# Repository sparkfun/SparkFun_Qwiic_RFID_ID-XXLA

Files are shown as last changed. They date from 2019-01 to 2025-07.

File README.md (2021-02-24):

SparkFun Qwiic RFID ID-XXLA
========================================

<table class="table table-hover table-striped table-bordered">
  <tr align="center">
   <td><a href="https://www.sparkfun.com/products/15191">RFID Qwiic Reader</a></td>
   <td><a href="https://www.sparkfun.com/products/15209">RFID Qwiic Kit</a></td>
  </tr>
  <tr align="center">
    <td><i>SparkFun RFID Qwiic Reader [<a href="https://www.sparkfun.com/products/15191">SEN-15191</a>]</i></td>
    <td><i>SparkFun RFID Qwiic Reader Kit [<a href="https://www.sparkfun.com/products/15209">KIT-15209</a>]<i></td>
  </tr>
</table>
     
The SparkFun Qwiic RFID ID-XXLA is a simple board that pairs with the ID-3LA, ID-12LA, ID-20LA, RFID modules.Utilizing the onboard ATtiny84A, the Qwiic RFID takes the six byte ID tag of your 125Khz RFID card, attaches a time stamp to it, and puts it onto a stack that holds up to 20 unique RFID scans at any given time. This information is easy to get at with some simple I2C commands and we’ve included some example code that shows you just how to do it using the broken out interrupt pin. We’ve also broken out two antennae pins that should only be used with the smaller ID-3LA.

The SparkFun Qwiic RFID has a buzzer and LED that indicates that card has been scanned. We’ve included a jumper to disconnect the buzzer, a jumper for the I2C pull-up resistors, an interrupt jumper, and finally an address jumper. The Qwiic RFID comes fully decked out in Qwiic connectors, no need to solder a thing, just plug it in and start scanning!

Repository Contents
-------------------

* **/Firmware** - The core sketch that runs the SparkFun Qwiic RFID ID-XXLA
* **/Arduino Examples** - A number of examples to show how to read buttons with time, change the I2C address and scan for I2C devices
* **/ATtiny Firmware** - Default firmware for the Qwiic RFID
* **/Hardware** - Eagle design files (.brd, .sch)

Documentation
--------------

* **[Hookup Guide](https://learn.sparkfun.com/tutorials/sparkfun-qwiic-rfid-idxxla-hookup-guide)** - Basic hookup guide.

Arduino Library 
----------------
* **[SparkFun Qwiic RFID Arduino Library](https://github.com/sparkfun/SparkFun_Qwiic_RFID_Arduino_Library)**

Python Package
----------------
* **[SparkFun Qwiic RFID Python Package](https://github.com/sparkfun/Qwiic_RFID_Py)**

Product Versions
----------------
* [SEN-15191](https://www.sparkfun.com/products/15191)- SparkFun Qwiic RFID ID-XXLA
* [KIT-15209](https://www.sparkfun.com/products/15209)- SparkFun Qwiic RFID ID-XXLA with ID Innovations RFID Module, Qwiic Cable, and RFID Tagged Cards, 

License Information
-------------------

This product is _**open source**_! 

Please review the LICENSE.md file for license information. 

If you have any questions or concerns on licensing, please contact techsupport@sparkfun.com.

Please use, reuse, and modify these files as you see fit. Please maintain attribution to SparkFun Electronics and release any derivative under the same license.

Distributed as-is; no warranty is given.

- Your friends at SparkFun.

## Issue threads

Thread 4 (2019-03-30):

Byts run together

pmartel, 2019-03-30:
### Subject of the issue
No separation between bytes in Example1_ReadTag.ino

### Your workbench
Windows 10, Arduino 1.6,6 and 1.8.9
* What version of the device are you using? Is there a firmware version?
USB
USB
* Are there any additional details that may help us help you?

### Steps to reproduce
Run it.  Notice that the bytes may be between 1 and 3 digits.  There is no clear separation between the bytes.
### Expected behaviour
Either put a separator between bytes, or express them in hex and put a '0' in front of '0' to 'f'
	for( int x = 0; x < TAG_REQUEST; x++ ) {
    tempTag = Wire.read();
    // Concatenating the bytes onto the end of "tagID".
    s = String(tempTag, HEX); // s is defined as a String
    if ( s.length() == 1) { // handle 00 through 0f
      s = "0"+s;
    }
    tagID += s;
  }
### Actual behaviour
bytes are ambiguous

edspark, 2019-04-01:
That's an interesting perspective. While the incoming bytes certainly could be broken up or printed out as a HEX, I don't see how that gives greater clarity to the RFID tag number because it _is_ that number. If you look at the datasheet for the module on the module's product page under the "Documents" tab found [here](https://www.sparkfun.com/products/11827). There is a section on page four that explains the format of the RFID tag number: five numerical values followed by a checksum of those five numbers. This is what's presented by the module to the SparkFun RFID IDxx-LA  and then passed to you the user.  It's like splitting the number 196 into it's individual numerical components (1 - 9 - 6), but really the number is 196.  Re-open the issue if I missed something. Thanks for issue!

pmartel, 2019-04-01:
Give that you know that there are 5 bytes and a checksum, I agree that you should be able to extract the bytes from a string of decimal digits.  However, if you want to verify the checksum, it becomes somewhat messy.
Here are the tag numbers for the 2 cards that came with my kit and another RFID device I have:
SparkFun Qwiic RFID, waiting for RFID to be scanned.
RFID Tag ID: 850898172147
RFID Tag ID: 850723432152
RFID Tag ID: 78097123228176

I wondered about the different lengths of the strings.  That led me to realize that there were no delimiters between the bytes and potential ambiguity.  If you had to take one of those RFID tag IDs and verify the checksum, how would you proceed?

edspark, 2019-04-02:
I like where you're brain is going! Before I begin, I want you to know that the module does a checksum on the bytes before it sends them serially to the SparkFun Qwiic RFID-IDxxLA, and then I unnecessarily do an _additional_ checksum on the number before I send it to the user. With that said, I would encourage you to read the datasheet (again page four) as it explains how it is done quite clearly with pictures, however I'll do my best to explain it in text.  Each column of bits of each _byte_ is exclusively or'ed (EXOR'ed) with each other to get the checksum.  If you wanted to get it done with provided code, you would print out each byte with the Serial.println(tempTag, BIN), then EXOR the first column of bits, then the second column bits, then the third, etc. and those EXOR'ed bits together will equal the sixth checksum byte.  Hope that helps.

pmartel, 2019-04-02:
Thanks, I'm familiar with checksums.  We used to do them on paper tape a long time ago.Given the individual bytes, it's straightforward to do a checksum, and of course the checksum of all 6 bytes should be 0.  I was just trying to point out that when the decimal representations of the bytes are merged together into a string, it's a bit tougher to verify the checksum.
Best wishes,--Phil
In a message dated 4/2/2019 12:44:45 Eastern Standard Time, notifications@github.com writes:

I like where you're brain is going! Before I begin, I want you to know that the module does a checksum on the bytes before it sends them serially to the SparkFun Qwiic RFID-IDxxLA, and then I unnecessarily do an additional checksum on the number before I send it to the user. With that said, I would encourage you to read the datasheet (again page four) as it explains how it is done quite clearly with pictures, however I'll do my best to explain it in text. Each column of bits of each byte is exclusively or'ed (EXOR'ed) with each other to get the checksum. If you wanted to get it done with provided code, you would print out each byte with the Serial.println(tempTag, BIN), then EXOR the first column of bits, then the second column bits, then the third, etc. and those EXOR'ed bits together will equal the sixth checksum byte. Hope that helps.

—
You are receiving this because you authored the thread.
Reply to this email directly, view it on GitHub, or mute the thread.

Closed 2019-04-01.

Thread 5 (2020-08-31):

FEATURE REQUEST: Detect if card is present

radimsejk, 2020-08-31:
This is not an issue but more of a feature request. I would like to be able to check if card is still present after the reading. Is there any way to do so or could you please add this feature to command set? My use case is some kind of capture the flag game. One card is left on the reader and program detects the time when someone steals the card and moves it to another base.  Thank you.

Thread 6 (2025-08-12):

Possible I2C address range in Library is different to Firmware

michaelheiml, 2025-08-12:
Library SparkFun_Qwiic_Rfid.cpp" seems to allow I2C addresses starting from 0x07 up to 0x78
```
141 if (newAddress < 0x07 || newAddress > 0x78) // Range of legal addresses
142        return false;
```
but the firmware only allows 0x08 to 0x07

https://github.com/sparkfun/SparkFun_Qwiic_RFID_ID-XXLA/blob/master/Firmware/ATtiny84_Firmware/Qwiic_RFID_IDXXLA/Qwiic_RFID_IDXXLA.ino
```
188 if (setting_i2c_address < 0x08 || setting_i2c_address > 0x77)
189          continue; //Command failed. This address is out of bounds.
```

This confused me a lot since I tried 0x07 without success for quite some time.. please fix.

Forum thread: https://community.sparkfun.com/t/qwiic-rfid-reader-change-i2c-address-cut-jumper-or-add-solder-blob/66483/3

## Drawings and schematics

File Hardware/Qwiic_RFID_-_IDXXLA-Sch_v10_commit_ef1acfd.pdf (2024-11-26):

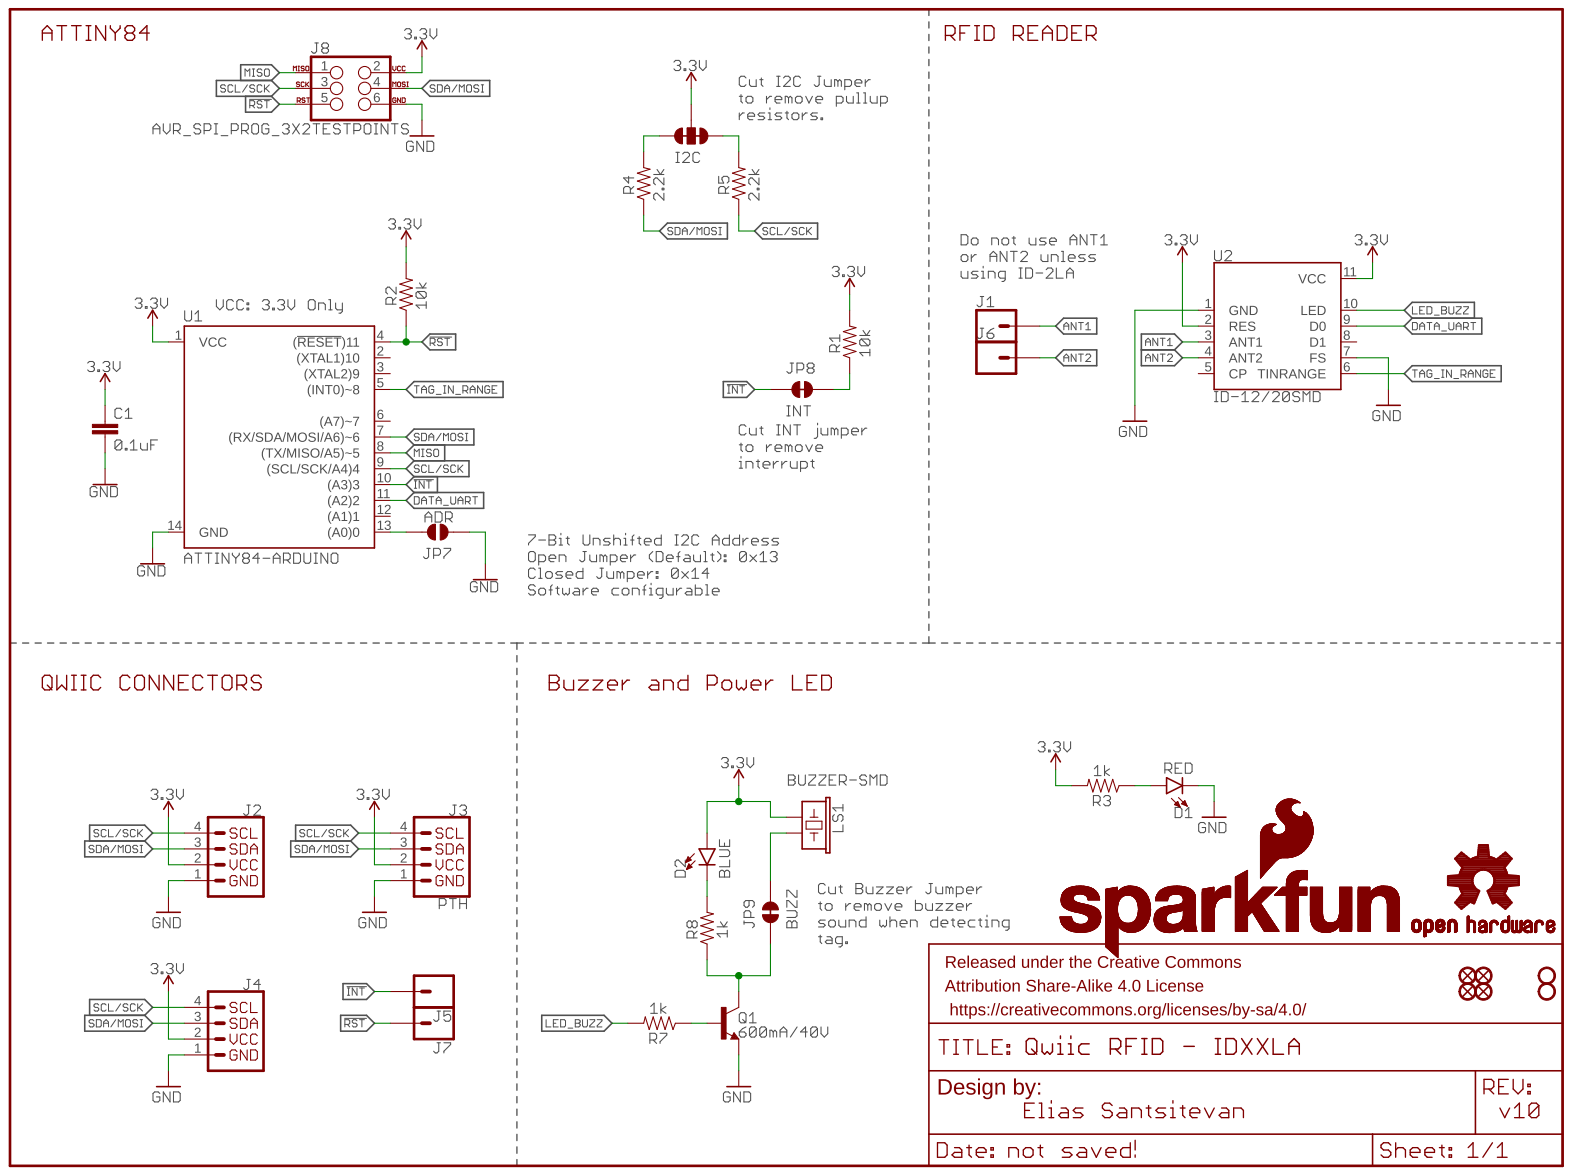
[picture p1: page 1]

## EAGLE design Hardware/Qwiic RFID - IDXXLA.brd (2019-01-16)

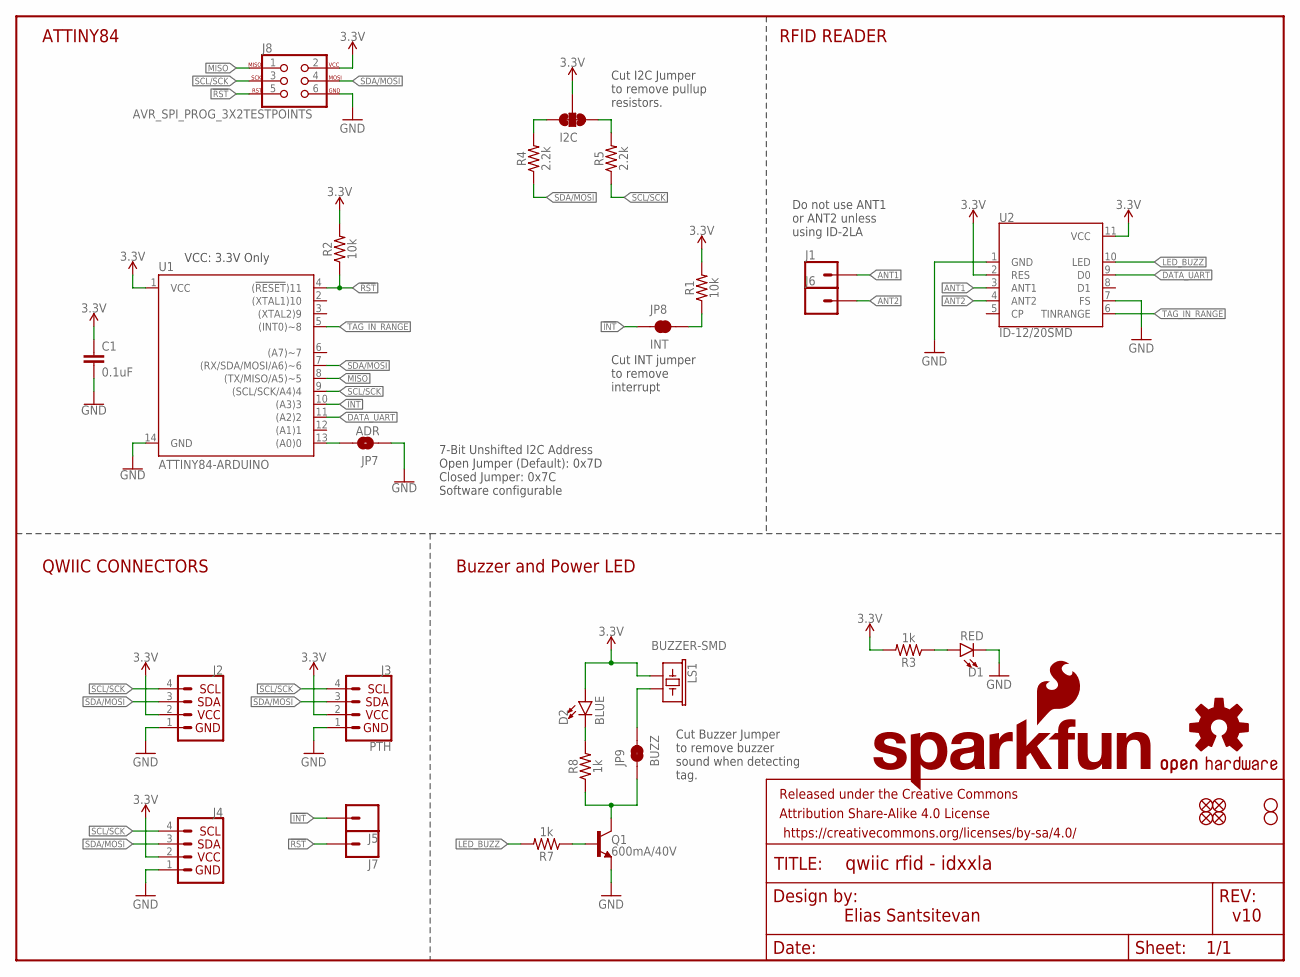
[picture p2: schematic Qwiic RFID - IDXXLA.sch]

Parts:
C1: 0.1uF; 0603
D1: RED; LED-0603
D2: BLUE; LED-0603
FRAME1: FRAME-LETTER; CREATIVE_COMMONS
I2C: JUMPER-SMT_3_2-NC_TRACE_SILK; SMT-JUMPER_3_2-NC_TRACE_SILK
J1, J5, J6, J7: CONN_01PTH_NO_SILK_YES_STOP; 1X01_NO_SILK
J2, J4: QWIIC_CONNECTORJS-1MM; 1X04_1MM_RA
J3: PTH; 1X04_NO_SILK
J8: AVR_SPI_PROG_3X2TESTPOINTS; 2X3_TEST_POINTS
JP1, JP2, JP5, JP6: FIDUCIALUFIDUCIAL; MICRO-FIDUCIAL
JP3, JP4: STAND-OFF
JP7: ADR; SMT-JUMPER_2_NO_SILK
JP8: INT; SMT-JUMPER_2_NC_TRACE_SILK
JP9: BUZZ; SMT-JUMPER_2_NC_TRACE_SILK
LOGO1: OSHW-LOGOMINI; OSHW-LOGO-MINI
LOGO3: SFE_LOGO_NAME_FLAME.1_INCH; SFE_LOGO_NAME_FLAME_.1
LS1: BUZZER-SMD; BUZZER-CCV
Q1: 600mA/40V; SOT23-3
R1, R2: 10k; 0603
R3, R7, R8: 1k; 0603
R4, R5: 2.2k; 0603
U1: ATTINY84-ARDUINO; SO14
U2: ID-12/20SMD; ID-12_SMD

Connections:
3.3V: C1.1, D2.A, I2C.2, J2.2, J3.2 (VCC), J4.2, J8.2, LS1.+ (1), R1.2, R2.2, R3.2, U1.1 (VCC), U2.2 (RES), U2.11 (VCC)
!INT: J5.1, JP8.1, U1.10 ((A3)3)
!RST: J7.1, J8.5, R2.1, U1.4 ((!RESET!)11)
ANT1: J1.1, U2.3 (ANT1)
ANT2: J6.1, U2.4 (ANT2)
DATA_UART: U1.11 ((A2)2), U2.9 (D0)
GND: C1.2, D1.C, J2.1, J3.1 (GND), J4.1, J8.6, JP7.1, Q1.2 (E), U1.14 (GND), U2.1 (GND), U2.7 (FS)
LED_BUZZ: R7.2, U2.10 (LED)
MISO: J8.1, U1.8 ((TX/MISO/A5)~5)
unnamed: I2C.1, R5.2
unnamed: I2C.3, R4.2
unnamed: D1.A, R3.1
unnamed: JP8.2, R1.1
unnamed: D2.C, R8.2
unnamed: JP7.2, U1.13 ((A0)0)
unnamed: Q1.1 (B), R7.1
unnamed: JP9.1, Q1.3 (C), R8.1
unnamed: JP9.2, LS1.- (2)
SCL/SCK: J2.4, J3.4 (SCL), J4.4, J8.3, R5.1, U1.9 ((SCL/SCK/A4)4)
SDA/MOSI: J2.3, J3.3 (SDA), J4.3, J8.4, R4.1, U1.7 ((RX/SDA/MOSI/A6)~6)
TAG_IN_RANGE: U1.5 ((INT0)~8), U2.6 (TINRANGE)

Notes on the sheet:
Buzzer and Power LED
RFID READER
ATTINY84
QWIIC CONNECTORS
7-Bit Unshifted I2C Address Open Jumper (Default): 0x7D Closed Jumper: 0x7C Software configurable
Cut Buzzer Jumper to remove buzzer sound when detecting tag.
Cut INT jumper to remove interrupt
Cut I2C Jumper to remove pullup resistors.
Do not use ANT1 or ANT2 unless using ID-2LA
v10
Elias Santsitevan
VCC: 3.3V Only

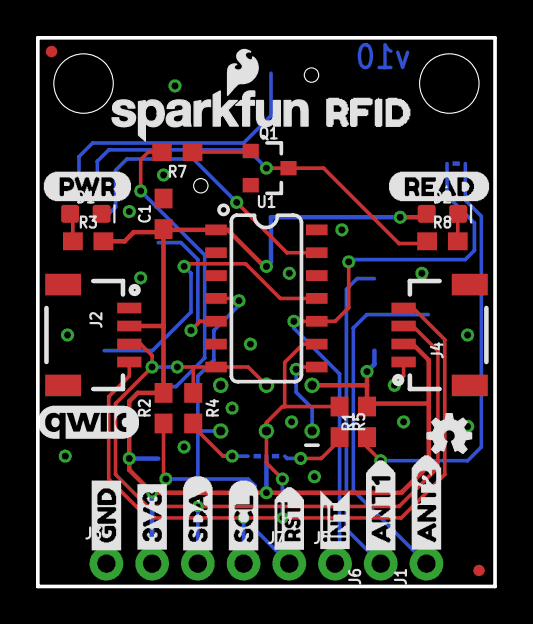
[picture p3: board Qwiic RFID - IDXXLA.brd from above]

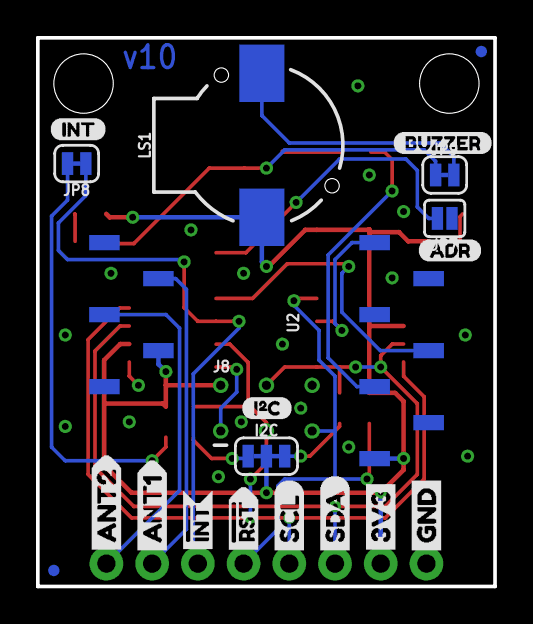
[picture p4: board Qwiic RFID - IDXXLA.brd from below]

Board: 2 copper layers, 25.4 x 30.5 mm, 59 parts (21 on the bottom side), 21 nets.

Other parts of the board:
U$1: QWIIC_COPYRIGHT_SMALL
U$2: I_SUPER2_C-()-03
U$3, U$17: ANT20
U$4: PWR-()-04
U$5, U$26: RST#-[>
U$6, U$23: SDA-[)
U$7, U$22: SCL-[)
U$8: RFID0
U$9, U$25: GND-04
U$10, U$24: 3V3-04
U$11, U$21: INT#-[<
U$12: ADR0
U$13: INT0
U$15: BUZZER0
U$16, U$20: ANT10
U$18: READ0

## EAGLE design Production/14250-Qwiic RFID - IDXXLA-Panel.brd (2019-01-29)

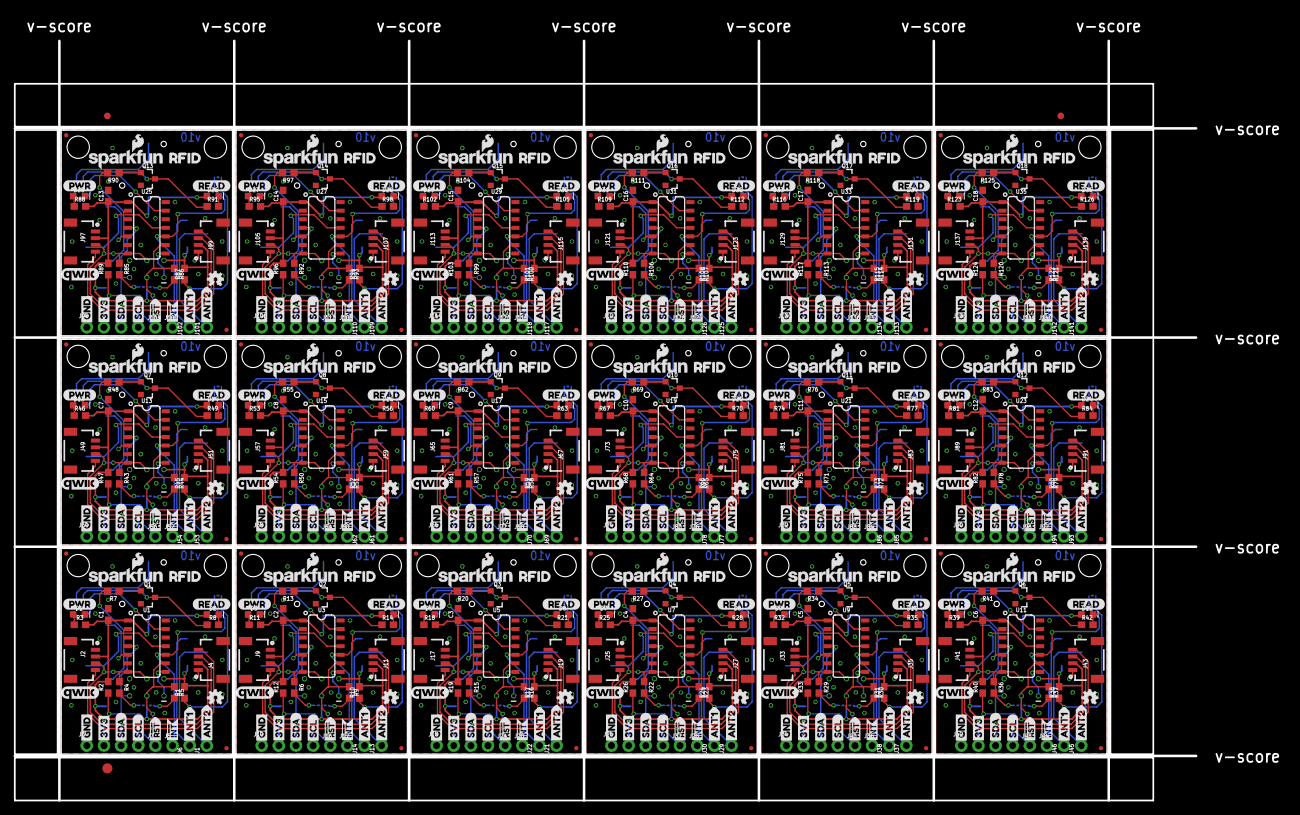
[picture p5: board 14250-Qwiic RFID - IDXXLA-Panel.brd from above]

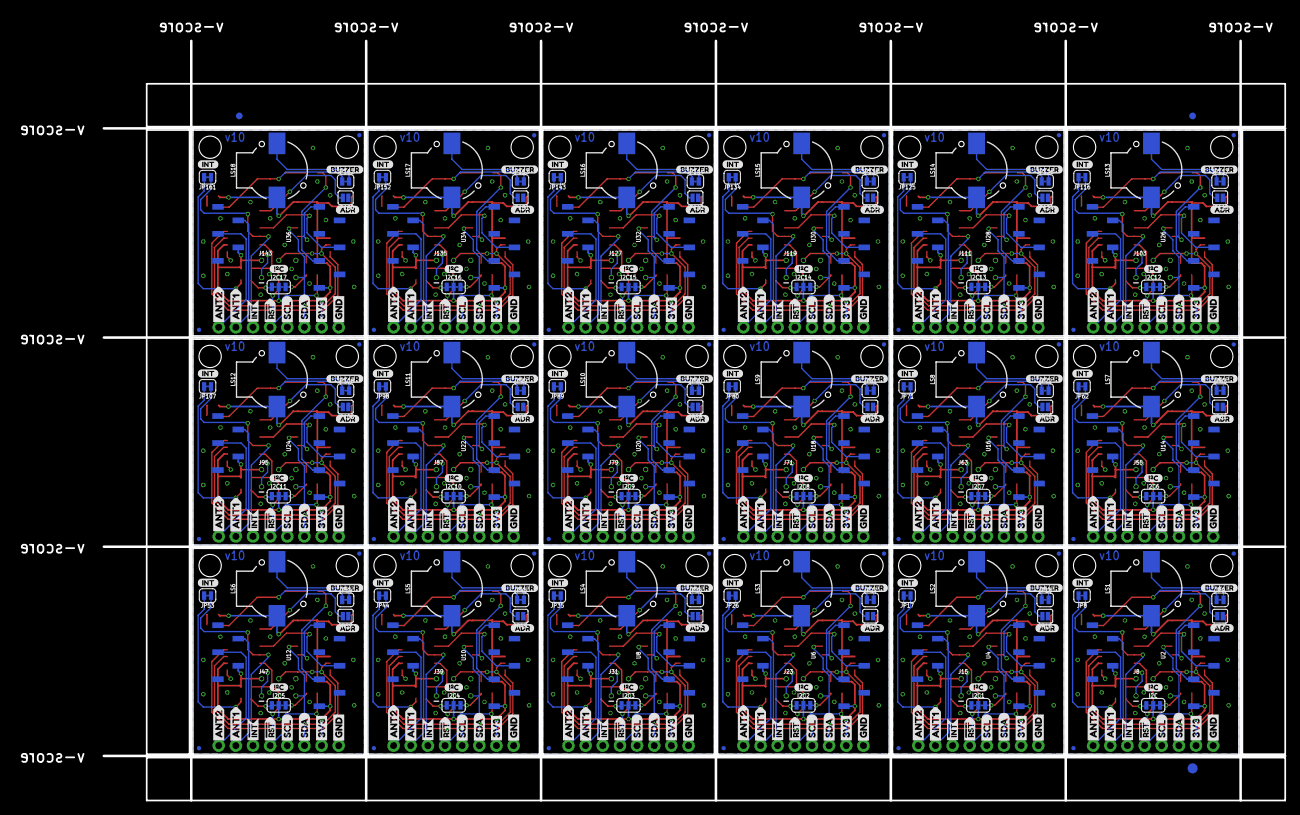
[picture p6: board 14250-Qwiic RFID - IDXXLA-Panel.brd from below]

Board: 2 copper layers, 175.0 x 112.5 mm, 1050 parts (381 on the bottom side), 378 nets.

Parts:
C1, C2, C3, C4, C5, C6, C7, C8, C9, C10, C11, C12, C13, C14, C15, C16, C17, C18: 0.1uF; 0603
D1, D3, D5, D7, D9, D11, D13, D15, D17, D19, D21, D23, D25, D27, D29, D31, D33, D35: RED; LED-0603
D2, D4, D6, D8, D10, D12, D14, D16, D18, D20, D22, D24, D26, D28, D30, D32, D34, D36: BLUE; LED-0603
E$1, E$2, E$3, E$4: FIDUCIAL-1X2
E$5, E$6: FIDUCIAL-1.5X3
I2C, I2C1, I2C2, I2C3, I2C4, I2C5, I2C6, I2C7, I2C8, I2C9, I2C10, I2C11, I2C12, I2C13, I2C14, I2C15, I2C16, I2C17: SMT-JUMPER_3_2-NC_TRACE_SILK
J1, J5, J6, J7, J12, J13, J14, J16, J20, J21, J22, J24, J28, J29, J30, J32, J36, J37, J38, J40, J44, J45, J46, J48, J52, J53, J54, J56, J60, J61, J62, J64, J68, J69, J70, J72, J76, J77, J78, J80, J84, J85, J86, J88, J92, J93, J94, J96, J100, J101, J102, J104, J108, J109, J110, J112, J116, J117, J118, J120, J124, J125, J126, J128, J132, J133, J134, J136, J140, J141, J142, J144: 1X01_NO_SILK
J2, J4, J9, J11, J17, J19, J25, J27, J33, J35, J41, J43, J49, J51, J57, J59, J65, J67, J73, J75, J81, J83, J89, J91, J97, J99, J105, J107, J113, J115, J121, J123, J129, J131, J137, J139: 1X04_1MM_RA
J3, J10, J18, J26, J34, J42, J50, J58, J66, J74, J82, J90, J98, J106, J114, J122, J130, J138: PTH; 1X04_NO_SILK
J8, J15, J23, J31, J39, J47, J55, J63, J71, J79, J87, J95, J103, J111, J119, J127, J135, J143: AVR_SPI_PROG_3X2TESTPOINTS; 2X3_TEST_POINTS
JP1, JP2, JP5, JP6, JP12, JP13, JP14, JP15, JP21, JP22, JP23, JP24, JP30, JP31, JP32, JP33, JP39, JP40, JP41, JP42, JP48, JP49, JP50, JP51, JP57, JP58, JP59, JP60, JP66, JP67, JP68, JP69, JP75, JP76, JP77, JP78, JP84, JP85, JP86, JP87, JP93, JP94, JP95, JP96, JP102, JP103, JP104, JP105, JP111, JP112, JP113, JP114, JP120, JP121, JP122, JP123, JP129, JP130, JP131, JP132, JP138, JP139, JP140, JP141, JP147, JP148, JP149, JP150, JP156, JP157, JP158, JP159: FIDUCIALUFIDUCIAL; MICRO-FIDUCIAL
JP3, JP4, JP10, JP11, JP19, JP20, JP28, JP29, JP37, JP38, JP46, JP47, JP55, JP56, JP64, JP65, JP73, JP74, JP82, JP83, JP91, JP92, JP100, JP101, JP109, JP110, JP118, JP119, JP127, JP128, JP136, JP137, JP145, JP146, JP154, JP155: STAND-OFF
JP7, JP16, JP25, JP34, JP43, JP52, JP61, JP70, JP79, JP88, JP97, JP106, JP115, JP124, JP133, JP142, JP151, JP160: ADR; SMT-JUMPER_2_NO_SILK
JP8, JP17, JP26, JP35, JP44, JP53, JP62, JP71, JP80, JP89, JP98, JP107, JP116, JP125, JP134, JP143, JP152, JP161: INT; SMT-JUMPER_2_NC_TRACE_SILK
JP9, JP18, JP27, JP36, JP45, JP54, JP63, JP72, JP81, JP90, JP99, JP108, JP117, JP126, JP135, JP144, JP153, JP162: BUZZ; SMT-JUMPER_2_NC_TRACE_SILK
LOGO1, LOGO2, LOGO5, LOGO7, LOGO9, LOGO11, LOGO13, LOGO15, LOGO17, LOGO19, LOGO21, LOGO23, LOGO25, LOGO27, LOGO29, LOGO31, LOGO33, LOGO35: OSHW-LOGOMINI; OSHW-LOGO-MINI
LOGO3, LOGO4, LOGO6, LOGO8, LOGO10, LOGO12, LOGO14, LOGO16, LOGO18, LOGO20, LOGO22, LOGO24, LOGO26, LOGO28, LOGO30, LOGO32, LOGO34, LOGO36: SFE_LOGO_NAME_FLAME.1_INCH; SFE_LOGO_NAME_FLAME_.1
LS1, LS2, LS3, LS4, LS5, LS6, LS7, LS8, LS9, LS10, LS11, LS12, LS13, LS14, LS15, LS16, LS17, LS18: BUZZER-SMD; BUZZER-CCV
Q1, Q2, Q3, Q4, Q5, Q6, Q7, Q8, Q9, Q10, Q11, Q12, Q13, Q14, Q15, Q16, Q17, Q18: 600mA/40V; SOT23-3
R1, R2, R10, R12, R17, R19, R24, R26, R31, R33, R38, R40, R45, R47, R52, R54, R59, R61, R66, R68, R73, R75, R80, R82, R87, R89, R94, R96, R101, R103, R108, R110, R115, R117, R122, R124: 10k; 0603
R3, R7, R8, R11, R13, R14, R18, R20, R21, R25, R27, R28, R32, R34, R35, R39, R41, R42, R46, R48, R49, R53, R55, R56, R60, R62, R63, R67, R69, R70, R74, R76, R77, R81, R83, R84, R88, R90, R91, R95, R97, R98, R102, R104, R105, R109, R111, R112, R116, R118, R119, R123, R125, R126: 1k; 0603
R4, R5, R6, R9, R15, R16, R22, R23, R29, R30, R36, R37, R43, R44, R50, R51, R57, R58, R64, R65, R71, R72, R78, R79, R85, R86, R92, R93, R99, R100, R106, R107, R113, R114, R120, R121: 2.2k; 0603
U1, U3, U5, U7, U9, U11, U13, U15, U17, U19, U21, U23, U25, U27, U29, U31, U33, U35: ATTINY84-ARDUINO; SO14
U2, U4, U6, U8, U10, U12, U14, U16, U18, U20, U22, U24, U26, U28, U30, U32, U34, U36: ID-12/20SMD; ID-12_SMD
U$1, U$47, U$71, U$95, U$119, U$143, U$167, U$191, U$215, U$239, U$263, U$287, U$311, U$335, U$359, U$383, U$407, U$431: QWIIC_COPYRIGHT_SMALL
U$2, U$43, U$67, U$91, U$115, U$139, U$163, U$187, U$211, U$235, U$259, U$283, U$307, U$331, U$355, U$379, U$403, U$427: I_SUPER2_C-()-03
U$3, U$17, U$33, U$35, U$57, U$59, U$81, U$83, U$105, U$107, U$129, U$131, U$153, U$155, U$177, U$179, U$201, U$203, U$225, U$227, U$249, U$251, U$273, U$275, U$297, U$299, U$321, U$323, U$345, U$347, U$369, U$371, U$393, U$395, U$417, U$419: ANT20
U$4, U$46, U$70, U$94, U$118, U$142, U$166, U$190, U$214, U$238, U$262, U$286, U$310, U$334, U$358, U$382, U$406, U$430: PWR-()-04
U$5, U$14, U$26, U$42, U$49, U$66, U$73, U$90, U$97, U$114, U$121, U$138, U$145, U$162, U$169, U$186, U$193, U$210, U$217, U$234, U$241, U$258, U$265, U$282, U$289, U$306, U$313, U$330, U$337, U$354, U$361, U$378, U$385, U$402, U$409, U$426: RST#-[>
U$6, U$19, U$23, U$39, U$50, U$63, U$74, U$87, U$98, U$111, U$122, U$135, U$146, U$159, U$170, U$183, U$194, U$207, U$218, U$231, U$242, U$255, U$266, U$279, U$290, U$303, U$314, U$327, U$338, U$351, U$362, U$375, U$386, U$399, U$410, U$423: SDA-[)
U$7, U$22, U$27, U$38, U$51, U$62, U$75, U$86, U$99, U$110, U$123, U$134, U$147, U$158, U$171, U$182, U$195, U$206, U$219, U$230, U$243, U$254, U$267, U$278, U$291, U$302, U$315, U$326, U$339, U$350, U$363, U$374, U$387, U$398, U$411, U$422: SCL-[)
U$8, U$48, U$72, U$96, U$120, U$144, U$168, U$192, U$216, U$240, U$264, U$288, U$312, U$336, U$360, U$384, U$408, U$432: RFID0
U$9, U$25, U$28, U$41, U$52, U$65, U$76, U$89, U$100, U$113, U$124, U$137, U$148, U$161, U$172, U$185, U$196, U$209, U$220, U$233, U$244, U$257, U$268, U$281, U$292, U$305, U$316, U$329, U$340, U$353, U$364, U$377, U$388, U$401, U$412, U$425: GND-04
U$10, U$24, U$29, U$40, U$53, U$64, U$77, U$88, U$101, U$112, U$125, U$136, U$149, U$160, U$173, U$184, U$197, U$208, U$221, U$232, U$245, U$256, U$269, U$280, U$293, U$304, U$317, U$328, U$341, U$352, U$365, U$376, U$389, U$400, U$413, U$424: 3V3-04
U$11, U$21, U$30, U$37, U$54, U$61, U$78, U$85, U$102, U$109, U$126, U$133, U$150, U$157, U$174, U$181, U$198, U$205, U$222, U$229, U$246, U$253, U$270, U$277, U$294, U$301, U$318, U$325, U$342, U$349, U$366, U$373, U$390, U$397, U$414, U$421: INT#-[<
U$12, U$44, U$68, U$92, U$116, U$140, U$164, U$188, U$212, U$236, U$260, U$284, U$308, U$332, U$356, U$380, U$404, U$428: ADR0
U$13, U$45, U$69, U$93, U$117, U$141, U$165, U$189, U$213, U$237, U$261, U$285, U$309, U$333, U$357, U$381, U$405, U$429: INT0
U$15, U$31, U$55, U$79, U$103, U$127, U$151, U$175, U$199, U$223, U$247, U$271, U$295, U$319, U$343, U$367, U$391, U$415: BUZZER0
U$16, U$20, U$32, U$36, U$56, U$60, U$80, U$84, U$104, U$108, U$128, U$132, U$152, U$156, U$176, U$180, U$200, U$204, U$224, U$228, U$248, U$252, U$272, U$276, U$296, U$300, U$320, U$324, U$344, U$348, U$368, U$372, U$392, U$396, U$416, U$420: ANT10
U$18, U$34, U$58, U$82, U$106, U$130, U$154, U$178, U$202, U$226, U$250, U$274, U$298, U$322, U$346, U$370, U$394, U$418: READ0

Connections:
3.3V: C1.1, D2.A, I2C.2, J2.2, J3.2, J4.2, J8.2, LS1.+, R1.2, R2.2, R3.2, U1.1, U2.2, U2.11
3.3V1: C2.1, D4.A, I2C1.2, J9.2, J10.2, J11.2, J15.2, LS2.+, R10.2, R11.2, R12.2, U3.1, U4.2, U4.11
3.3V2: C3.1, D6.A, I2C2.2, J17.2, J18.2, J19.2, J23.2, LS3.+, R17.2, R18.2, R19.2, U5.1, U6.2, U6.11
3.3V3: C4.1, D8.A, I2C3.2, J25.2, J26.2, J27.2, J31.2, LS4.+, R24.2, R25.2, R26.2, U7.1, U8.2, U8.11
3.3V4: C5.1, D10.A, I2C4.2, J33.2, J34.2, J35.2, J39.2, LS5.+, R31.2, R32.2, R33.2, U9.1, U10.2, U10.11
3.3V5: C6.1, D12.A, I2C5.2, J41.2, J42.2, J43.2, J47.2, LS6.+, R38.2, R39.2, R40.2, U11.1, U12.2, U12.11
3.3V6: C7.1, D14.A, I2C6.2, J49.2, J50.2, J51.2, J55.2, LS7.+, R45.2, R46.2, R47.2, U13.1, U14.2, U14.11
3.3V7: C8.1, D16.A, I2C7.2, J57.2, J58.2, J59.2, J63.2, LS8.+, R52.2, R53.2, R54.2, U15.1, U16.2, U16.11
3.3V8: C9.1, D18.A, I2C8.2, J65.2, J66.2, J67.2, J71.2, LS9.+, R59.2, R60.2, R61.2, U17.1, U18.2, U18.11
3.3V9: C10.1, D20.A, I2C9.2, J73.2, J74.2, J75.2, J79.2, LS10.+, R66.2, R67.2, R68.2, U19.1, U20.2, U20.11
3.3V10: C11.1, D22.A, I2C10.2, J81.2, J82.2, J83.2, J87.2, LS11.+, R73.2, R74.2, R75.2, U21.1, U22.2, U22.11
3.3V11: C12.1, D24.A, I2C11.2, J89.2, J90.2, J91.2, J95.2, LS12.+, R80.2, R81.2, R82.2, U23.1, U24.2, U24.11
3.3V12: C13.1, D26.A, I2C12.2, J97.2, J98.2, J99.2, J103.2, LS13.+, R87.2, R88.2, R89.2, U25.1, U26.2, U26.11
3.3V13: C14.1, D28.A, I2C13.2, J105.2, J106.2, J107.2, J111.2, LS14.+, R94.2, R95.2, R96.2, U27.1, U28.2, U28.11
3.3V14: C15.1, D30.A, I2C14.2, J113.2, J114.2, J115.2, J119.2, LS15.+, R101.2, R102.2, R103.2, U29.1, U30.2, U30.11
3.3V15: C16.1, D32.A, I2C15.2, J121.2, J122.2, J123.2, J127.2, LS16.+, R108.2, R109.2, R110.2, U31.1, U32.2, U32.11
3.3V16: C17.1, D34.A, I2C16.2, J129.2, J130.2, J131.2, J135.2, LS17.+, R115.2, R116.2, R117.2, U33.1, U34.2, U34.11
3.3V17: C18.1, D36.A, I2C17.2, J137.2, J138.2, J139.2, J143.2, LS18.+, R122.2, R123.2, R124.2, U35.1, U36.2, U36.11
!INT: J5.1, JP8.1, U1.10
!INT1: J12.1, JP17.1, U3.10
!INT2: J20.1, JP26.1, U5.10
!INT3: J28.1, JP35.1, U7.10
!INT4: J36.1, JP44.1, U9.10
!INT5: J44.1, JP53.1, U11.10
!INT6: J52.1, JP62.1, U13.10
!INT7: J60.1, JP71.1, U15.10
!INT8: J68.1, JP80.1, U17.10
!INT9: J76.1, JP89.1, U19.10
!INT10: J84.1, JP98.1, U21.10
!INT11: J92.1, JP107.1, U23.10
!INT12: J100.1, JP116.1, U25.10
!INT13: J108.1, JP125.1, U27.10
!INT14: J116.1, JP134.1, U29.10
!INT15: J124.1, JP143.1, U31.10
!INT16: J132.1, JP152.1, U33.10
!INT17: J140.1, JP161.1, U35.10
!RST: J7.1, J8.5, R2.1, U1.4
!RST1: J15.5, J16.1, R12.1, U3.4
!RST2: J23.5, J24.1, R19.1, U5.4
!RST3: J31.5, J32.1, R26.1, U7.4
!RST4: J39.5, J40.1, R33.1, U9.4
!RST5: J47.5, J48.1, R40.1, U11.4
!RST6: J55.5, J56.1, R47.1, U13.4
!RST7: J63.5, J64.1, R54.1, U15.4
!RST8: J71.5, J72.1, R61.1, U17.4
!RST9: J79.5, J80.1, R68.1, U19.4
!RST10: J87.5, J88.1, R75.1, U21.4
!RST11: J95.5, J96.1, R82.1, U23.4
!RST12: J103.5, J104.1, R89.1, U25.4
!RST13: J111.5, J112.1, R96.1, U27.4
!RST14: J119.5, J120.1, R103.1, U29.4
!RST15: J127.5, J128.1, R110.1, U31.4
!RST16: J135.5, J136.1, R117.1, U33.4
!RST17: J143.5, J144.1, R124.1, U35.4
ANT1: J1.1, U2.3
ANT2: J6.1, U2.4
ANT3: J13.1, U4.3
ANT4: J14.1, U4.4
ANT5: J21.1, U6.3
ANT6: J22.1, U6.4
ANT7: J29.1, U8.3
ANT8: J30.1, U8.4
ANT9: J37.1, U10.3
ANT10: J38.1, U10.4
ANT11: J45.1, U12.3
ANT12: J46.1, U12.4
ANT13: J53.1, U14.3
ANT14: J54.1, U14.4
ANT15: J61.1, U16.3
ANT16: J62.1, U16.4
ANT17: J69.1, U18.3
ANT18: J70.1, U18.4
ANT19: J77.1, U20.3
ANT20: J78.1, U20.4
ANT21: J85.1, U22.3
ANT22: J86.1, U22.4
ANT23: J93.1, U24.3
ANT24: J94.1, U24.4
ANT25: J101.1, U26.3
ANT26: J102.1, U26.4
ANT27: J109.1, U28.3
ANT28: J110.1, U28.4
ANT29: J117.1, U30.3
ANT30: J118.1, U30.4
ANT31: J125.1, U32.3
ANT32: J126.1, U32.4
ANT33: J133.1, U34.3
ANT34: J134.1, U34.4
ANT35: J141.1, U36.3
ANT36: J142.1, U36.4
DATA_UART: U1.11, U2.9
DATA_UART1: U3.11, U4.9
DATA_UART2: U5.11, U6.9
DATA_UART3: U7.11, U8.9
DATA_UART4: U9.11, U10.9
DATA_UART5: U11.11, U12.9
DATA_UART6: U13.11, U14.9
DATA_UART7: U15.11, U16.9
DATA_UART8: U17.11, U18.9
DATA_UART9: U19.11, U20.9
DATA_UART10: U21.11, U22.9
DATA_UART11: U23.11, U24.9
DATA_UART12: U25.11, U26.9
DATA_UART13: U27.11, U28.9
DATA_UART14: U29.11, U30.9
DATA_UART15: U31.11, U32.9
DATA_UART16: U33.11, U34.9
DATA_UART17: U35.11, U36.9
GND: C1.2, D1.C, J2.1, J3.1, J4.1, J8.6, JP7.1, Q1.2, U1.14, U2.1, U2.7
GND1: C2.2, D3.C, J9.1, J10.1, J11.1, J15.6, JP16.1, Q2.2, U3.14, U4.1, U4.7
GND2: C3.2, D5.C, J17.1, J18.1, J19.1, J23.6, JP25.1, Q3.2, U5.14, U6.1, U6.7
GND3: C4.2, D7.C, J25.1, J26.1, J27.1, J31.6, JP34.1, Q4.2, U7.14, U8.1, U8.7
GND4: C5.2, D9.C, J33.1, J34.1, J35.1, J39.6, JP43.1, Q5.2, U9.14, U10.1, U10.7
GND5: C6.2, D11.C, J41.1, J42.1, J43.1, J47.6, JP52.1, Q6.2, U11.14, U12.1, U12.7
GND6: C7.2, D13.C, J49.1, J50.1, J51.1, J55.6, JP61.1, Q7.2, U13.14, U14.1, U14.7
GND7: C8.2, D15.C, J57.1, J58.1, J59.1, J63.6, JP70.1, Q8.2, U15.14, U16.1, U16.7
GND8: C9.2, D17.C, J65.1, J66.1, J67.1, J71.6, JP79.1, Q9.2, U17.14, U18.1, U18.7
GND9: C10.2, D19.C, J73.1, J74.1, J75.1, J79.6, JP88.1, Q10.2, U19.14, U20.1, U20.7
GND10: C11.2, D21.C, J81.1, J82.1, J83.1, J87.6, JP97.1, Q11.2, U21.14, U22.1, U22.7
GND11: C12.2, D23.C, J89.1, J90.1, J91.1, J95.6, JP106.1, Q12.2, U23.14, U24.1, U24.7
GND12: C13.2, D25.C, J97.1, J98.1, J99.1, J103.6, JP115.1, Q13.2, U25.14, U26.1, U26.7
GND13: C14.2, D27.C, J105.1, J106.1, J107.1, J111.6, JP124.1, Q14.2, U27.14, U28.1, U28.7
GND14: C15.2, D29.C, J113.1, J114.1, J115.1, J119.6, JP133.1, Q15.2, U29.14, U30.1, U30.7
GND15: C16.2, D31.C, J121.1, J122.1, J123.1, J127.6, JP142.1, Q16.2, U31.14, U32.1, U32.7
GND16: C17.2, D33.C, J129.1, J130.1, J131.1, J135.6, JP151.1, Q17.2, U33.14, U34.1, U34.7
GND17: C18.2, D35.C, J137.1, J138.1, J139.1, J143.6, JP160.1, Q18.2, U35.14, U36.1, U36.7
LED_BUZZ: R7.2, U2.10
LED_BUZZ1: R13.2, U4.10
LED_BUZZ2: R20.2, U6.10
LED_BUZZ3: R27.2, U8.10
LED_BUZZ4: R34.2, U10.10
LED_BUZZ5: R41.2, U12.10
LED_BUZZ6: R48.2, U14.10
LED_BUZZ7: R55.2, U16.10
LED_BUZZ8: R62.2, U18.10
LED_BUZZ9: R69.2, U20.10
LED_BUZZ10: R76.2, U22.10
LED_BUZZ11: R83.2, U24.10
LED_BUZZ12: R90.2, U26.10
LED_BUZZ13: R97.2, U28.10
LED_BUZZ14: R104.2, U30.10
LED_BUZZ15: R111.2, U32.10
LED_BUZZ16: R118.2, U34.10
LED_BUZZ17: R125.2, U36.10
MISO: J8.1, U1.8
MISO1: J15.1, U3.8
MISO2: J23.1, U5.8
MISO3: J31.1, U7.8
MISO4: J39.1, U9.8
MISO5: J47.1, U11.8
MISO6: J55.1, U13.8
MISO7: J63.1, U15.8
MISO8: J71.1, U17.8
MISO9: J79.1, U19.8
MISO10: J87.1, U21.8
MISO11: J95.1, U23.8
MISO12: J103.1, U25.8
MISO13: J111.1, U27.8
MISO14: J119.1, U29.8
MISO15: J127.1, U31.8
MISO16: J135.1, U33.8
MISO17: J143.1, U35.8
unnamed: I2C.1, R5.2
unnamed: I2C.3, R4.2
unnamed: D1.A, R3.1
unnamed: JP8.2, R1.1
unnamed: D2.C, R8.2
unnamed: JP7.2, U1.13
unnamed: Q1.1, R7.1
unnamed: JP9.1, Q1.3, R8.1
unnamed: JP9.2, LS1.-
unnamed: I2C1.1, R9.2
unnamed: D3.A, R11.1
unnamed: JP16.2, U3.13
unnamed: I2C1.3, R6.2
unnamed: JP17.2, R10.1
unnamed: Q2.1, R13.1
unnamed: JP18.1, Q2.3, R14.1
unnamed: D4.C, R14.2
unnamed: JP18.2, LS2.-
unnamed: I2C2.1, R16.2
unnamed: D5.A, R18.1
unnamed: JP25.2, U5.13
unnamed: I2C2.3, R15.2
unnamed: JP26.2, R17.1
unnamed: Q3.1, R20.1
unnamed: JP27.1, Q3.3, R21.1
unnamed: D6.C, R21.2
unnamed: JP27.2, LS3.-
unnamed: I2C3.1, R23.2
unnamed: D7.A, R25.1
unnamed: JP34.2, U7.13
unnamed: I2C3.3, R22.2
unnamed: JP35.2, R24.1
unnamed: Q4.1, R27.1
unnamed: JP36.1, Q4.3, R28.1
unnamed: D8.C, R28.2
unnamed: JP36.2, LS4.-
unnamed: I2C4.1, R30.2
unnamed: D9.A, R32.1
unnamed: JP43.2, U9.13
unnamed: I2C4.3, R29.2
unnamed: JP44.2, R31.1
unnamed: Q5.1, R34.1
unnamed: JP45.1, Q5.3, R35.1
unnamed: D10.C, R35.2
unnamed: JP45.2, LS5.-
unnamed: I2C5.1, R37.2
unnamed: D11.A, R39.1
unnamed: JP52.2, U11.13
unnamed: I2C5.3, R36.2
unnamed: JP53.2, R38.1
unnamed: Q6.1, R41.1
unnamed: JP54.1, Q6.3, R42.1
unnamed: D12.C, R42.2
unnamed: JP54.2, LS6.-
unnamed: I2C6.1, R44.2
unnamed: D13.A, R46.1
unnamed: JP61.2, U13.13
unnamed: I2C6.3, R43.2
unnamed: JP62.2, R45.1
unnamed: Q7.1, R48.1
unnamed: JP63.1, Q7.3, R49.1
unnamed: D14.C, R49.2
unnamed: JP63.2, LS7.-
unnamed: I2C7.1, R51.2
unnamed: D15.A, R53.1
unnamed: JP70.2, U15.13
unnamed: I2C7.3, R50.2
unnamed: JP71.2, R52.1
unnamed: Q8.1, R55.1
unnamed: JP72.1, Q8.3, R56.1
unnamed: D16.C, R56.2
unnamed: JP72.2, LS8.-
unnamed: I2C8.1, R58.2
unnamed: D17.A, R60.1
unnamed: JP79.2, U17.13
unnamed: I2C8.3, R57.2
unnamed: JP80.2, R59.1
unnamed: Q9.1, R62.1
unnamed: JP81.1, Q9.3, R63.1
unnamed: D18.C, R63.2
unnamed: JP81.2, LS9.-
unnamed: I2C9.1, R65.2
unnamed: D19.A, R67.1
unnamed: JP88.2, U19.13
unnamed: I2C9.3, R64.2
unnamed: JP89.2, R66.1
unnamed: Q10.1, R69.1
unnamed: JP90.1, Q10.3, R70.1
unnamed: D20.C, R70.2
unnamed: JP90.2, LS10.-
unnamed: I2C10.1, R72.2
unnamed: D21.A, R74.1
unnamed: JP97.2, U21.13
unnamed: I2C10.3, R71.2
unnamed: JP98.2, R73.1
unnamed: Q11.1, R76.1
unnamed: JP99.1, Q11.3, R77.1
unnamed: D22.C, R77.2
unnamed: JP99.2, LS11.-
unnamed: I2C11.1, R79.2
unnamed: D23.A, R81.1
unnamed: JP106.2, U23.13
unnamed: I2C11.3, R78.2
unnamed: JP107.2, R80.1
unnamed: Q12.1, R83.1
unnamed: JP108.1, Q12.3, R84.1
unnamed: D24.C, R84.2
unnamed: JP108.2, LS12.-
unnamed: I2C12.1, R86.2
unnamed: D25.A, R88.1
unnamed: JP115.2, U25.13
unnamed: I2C12.3, R85.2
unnamed: JP116.2, R87.1
unnamed: Q13.1, R90.1
unnamed: JP117.1, Q13.3, R91.1
unnamed: D26.C, R91.2
unnamed: JP117.2, LS13.-
unnamed: I2C13.1, R93.2
unnamed: D27.A, R95.1
unnamed: JP124.2, U27.13
unnamed: I2C13.3, R92.2
unnamed: JP125.2, R94.1
unnamed: Q14.1, R97.1
unnamed: JP126.1, Q14.3, R98.1
unnamed: D28.C, R98.2
unnamed: JP126.2, LS14.-
unnamed: I2C14.1, R100.2
unnamed: D29.A, R102.1
unnamed: JP133.2, U29.13
unnamed: I2C14.3, R99.2
unnamed: JP134.2, R101.1
unnamed: Q15.1, R104.1
unnamed: JP135.1, Q15.3, R105.1
unnamed: D30.C, R105.2
unnamed: JP135.2, LS15.-
unnamed: I2C15.1, R107.2
unnamed: D31.A, R109.1
unnamed: JP142.2, U31.13
unnamed: I2C15.3, R106.2
unnamed: JP143.2, R108.1
unnamed: Q16.1, R111.1
unnamed: JP144.1, Q16.3, R112.1
unnamed: D32.C, R112.2
unnamed: JP144.2, LS16.-
unnamed: I2C16.1, R114.2
unnamed: D33.A, R116.1
unnamed: JP151.2, U33.13
unnamed: I2C16.3, R113.2
unnamed: JP152.2, R115.1
unnamed: Q17.1, R118.1
unnamed: JP153.1, Q17.3, R119.1
unnamed: D34.C, R119.2
unnamed: JP153.2, LS17.-
unnamed: I2C17.1, R121.2
unnamed: D35.A, R123.1
unnamed: JP160.2, U35.13
unnamed: I2C17.3, R120.2
unnamed: JP161.2, R122.1
unnamed: Q18.1, R125.1
unnamed: JP162.1, Q18.3, R126.1
unnamed: D36.C, R126.2
unnamed: JP162.2, LS18.-
SCL/SCK: J2.4, J3.4, J4.4, J8.3, R5.1, U1.9
SCL/SCK1: J9.4, J10.4, J11.4, J15.3, R9.1, U3.9
SCL/SCK2: J17.4, J18.4, J19.4, J23.3, R16.1, U5.9
SCL/SCK3: J25.4, J26.4, J27.4, J31.3, R23.1, U7.9
SCL/SCK4: J33.4, J34.4, J35.4, J39.3, R30.1, U9.9
SCL/SCK5: J41.4, J42.4, J43.4, J47.3, R37.1, U11.9
SCL/SCK6: J49.4, J50.4, J51.4, J55.3, R44.1, U13.9
SCL/SCK7: J57.4, J58.4, J59.4, J63.3, R51.1, U15.9
SCL/SCK8: J65.4, J66.4, J67.4, J71.3, R58.1, U17.9
SCL/SCK9: J73.4, J74.4, J75.4, J79.3, R65.1, U19.9
SCL/SCK10: J81.4, J82.4, J83.4, J87.3, R72.1, U21.9
SCL/SCK11: J89.4, J90.4, J91.4, J95.3, R79.1, U23.9
SCL/SCK12: J97.4, J98.4, J99.4, J103.3, R86.1, U25.9
SCL/SCK13: J105.4, J106.4, J107.4, J111.3, R93.1, U27.9
SCL/SCK14: J113.4, J114.4, J115.4, J119.3, R100.1, U29.9
SCL/SCK15: J121.4, J122.4, J123.4, J127.3, R107.1, U31.9
SCL/SCK16: J129.4, J130.4, J131.4, J135.3, R114.1, U33.9
SCL/SCK17: J137.4, J138.4, J139.4, J143.3, R121.1, U35.9
SDA/MOSI: J2.3, J3.3, J4.3, J8.4, R4.1, U1.7
SDA/MOSI1: J9.3, J10.3, J11.3, J15.4, R6.1, U3.7
SDA/MOSI2: J17.3, J18.3, J19.3, J23.4, R15.1, U5.7
SDA/MOSI3: J25.3, J26.3, J27.3, J31.4, R22.1, U7.7
SDA/MOSI4: J33.3, J34.3, J35.3, J39.4, R29.1, U9.7
SDA/MOSI5: J41.3, J42.3, J43.3, J47.4, R36.1, U11.7
SDA/MOSI6: J49.3, J50.3, J51.3, J55.4, R43.1, U13.7
SDA/MOSI7: J57.3, J58.3, J59.3, J63.4, R50.1, U15.7
SDA/MOSI8: J65.3, J66.3, J67.3, J71.4, R57.1, U17.7
SDA/MOSI9: J73.3, J74.3, J75.3, J79.4, R64.1, U19.7
SDA/MOSI10: J81.3, J82.3, J83.3, J87.4, R71.1, U21.7
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

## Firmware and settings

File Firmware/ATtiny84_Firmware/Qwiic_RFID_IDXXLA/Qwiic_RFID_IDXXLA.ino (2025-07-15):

/*
  An I2C based KeyPad
  By: Elias Santistevan
  SparkFun Electronics
  Date: 2018
  License: This code is public domain but you buy me a beer if you use this and we meet someday (Beerware license).

  Feel like supporting our work? Buy a board from SparkFun!
	<Product Page Here>

  To install support for ATtiny84 in Arduino IDE: https://github.com/SpenceKonde/ATTinyCore/blob/master/Installation.md
  This core is installed from the Board Manager menu
  This core has built in support for I2C S/M and serial
  If you have Dave Mellis' ATtiny installed you may need to remove it from \Users\xx\AppData\Local\Arduino15\Packages

  To support 400kHz I2C communication reliably ATtiny84 needs to run at 8MHz. This requires user to
  click on 'Burn Bootloader' before code is loaded.
*/

#include <Wire.h>

#include <EEPROM.h>

#include <SoftwareSerial.h>

#include <avr/sleep.h>
#include <avr/power.h> 

#define LOCATION_I2C_ADDRESS 0x01 //Location in EEPROM where the I2C address is stored
#define I2C_ADDRESS_DEFAULT 0x13 
#define I2C_ADDRESS_NO_JUMPER 0x14 

#define COMMAND_CHANGE_ADDRESS 0xC7

volatile byte setting_i2c_address = I2C_ADDRESS_DEFAULT; 

volatile byte responseSize = 10; 
//6 byte ID, followed by 4 bytes of time used to pass data back to master
byte responseBuffer[10]; 

//This struct keeps a record of any tag 'events' i.e. reads. 
//This includes the 10 byte Ascii tag ID, 2 byte Checksum, and the 4 other bytes listed below.
#define TAG_ID_SIZE 16 
#define MAX_TAG_STORAGE 20 //How many tags will be held at a time before the first is overwritten.
struct {
  byte tagID[6]; //The Uniqe identifier of the RFID tag, converted from ASCII to HEX will be six bytes in size.
  unsigned long tagTime; //When was the RFID tag sensed?
} tagEvent[MAX_TAG_STORAGE];

volatile byte newestTag = 0;
volatile byte oldestTag = 0;

const byte addrPin = 0; 
const byte interruptPin = 3; //Pin goes low when a tag event is available
const byte resetPin = 11; 

const byte rxPin = 2; 
const byte txPin = 1; //TX Pin is unconnected, unused, and unnecessary except for Software Serial declaration.

SoftwareSerial atSerial = SoftwareSerial(rxPin, txPin); 

const byte startByte = 0x2; //Beginning Transmission Hex value 
const byte endByte = 0x3; //Ending Transmission Hex value
const byte cRHex = 0xD; //Carriage Return Hex
const byte lFHex = 0xA; //Line Follower Hex 

byte tempInc[TAG_ID_SIZE]; 
byte tempTagID[6];

void setup(void)
{
  pinMode(addrPin, INPUT_PULLUP); //Default HIGH = 0x13
  pinMode(interruptPin, OUTPUT); //Tied high and goes low when an RFID has been scanned.

  pinMode(rxPin, INPUT); 
  pinMode(txPin, OUTPUT); 
	atSerial.begin(9600); //Baud requirement for the ID Module

  //Disable ADC
  ADCSRA = 0;
  //Disble Brown-Out Detect
  MCUCR = bit (BODS) | bit (BODSE);
  MCUCR = bit (BODS);

  //Power down various bits of hardware to lower power usage
  //set_sleep_mode(SLEEP_MODE_PWR_DOWN);
  set_sleep_mode(SLEEP_MODE_IDLE);
  sleep_enable();

  readSystemSettings(); //Load all system settings from EEPROM

  startI2C(); //Determine the I2C address we should be using and begin listening on I2C bus
}

void loop(void)
{
  //Waiting for new RFID cards/capsules to be scanned. 
  if( atSerial.available() )
	{
		while( atSerial.available() ) 
		{	
			if( atSerial.read() != startByte ) break; 
			delay(11);//Necessary to not overwhelm the ID-XXLA module baud rate.
			if( getTagID() ) tagEvent[newestTag].tagTime = millis(); //Get the Tag ID, and verify its' contents, then grab time. 
		}
		if( ++newestTag== MAX_TAG_STORAGE ) newestTag = 0; 
	}

  //Set interrupt pin as needed
  if(newestTag != oldestTag	)
    digitalWrite(interruptPin, LOW); //We have tags on the stack!
  else
    digitalWrite(interruptPin, HIGH); //No tag events to report

  sleep_mode(); //Stop everything and go to sleep. Wake up if I2C event occurs.
}

// We want to convert the tag from it's Ascii representation of a HEX value from the module 
// (12 bytes) to the actual HEX value (6 bytes). The Ascii value is saved into a temporary array 
// and the individual elements of the temporary array are passed to another function where they 
// are converted to the decimal equivalent values and saved into another temporaray array. The value
// is validated and then passed into the final array ready to be sent on the I2C bus.
bool getTagID() 
{
	int j = 0; 
	for( int i = 0; i < TAG_ID_SIZE - 1 ; i ++ ) //TAG_ID_SIZE IS 16, but an index is numerically one less (0-15).
	{
		tempInc[i] = atSerial.read(); 	
		delay(11); //The delay keeps the read commands from outpacing the baud rate of 9600.
	}
	for( int i = 0; i < TAG_ID_SIZE - 1; i ++ ) 
	{
		if( i % 2 == 0 && i !=0 ) j++; 
		if( tempInc[i] == endByte ) break;
		else if( i > 10 && (tempInc[i] == cRHex || tempInc[i] == lFHex)) continue; //Not part of the TAG ID
		else if( i % 2 == 0 ) tempTagID[j] = convertAscii(tempInc[i]) << 4; //MSB
		else ( tempTagID[j] |= convertAscii(tempInc[i]) );//LSB
	}
	j=0;

	if( checkSum(tempTagID) )
	{
		for( int i = 0; i < 6; i++ )
		{
			tagEvent[newestTag].tagID[i] = tempTagID[i];
		}
		return true; 
	} 
	else return false; 
}

// Changes Ascii Values to their decimal representation by subtracting a fixed
// number, best understood by taking a look at an Ascii table. For example: we're 
// changing an Ascii zero, to an actual zero: ASCII "0" = 48 decimal.
byte convertAscii(byte asciiVal)
{
	if( asciiVal >= '0' && asciiVal <= '9' ) return asciiVal -= 48; 
	else if( asciiVal >= 'A' && asciiVal <= 'F' ) return asciiVal -= 55; 
}

//Double checking checksum value given by the tag module just in case something went wrong along the way.
bool checkSum(byte* uncheckedTag)
{
	byte exOr = uncheckedTag[0]; 
	for( int i = 1; i < 5 ; i ++)
	{
		exOr ^= uncheckedTag[i];
	}
	if( exOr == uncheckedTag[5] ) return true; 
	else return false;
}


void receiveEvent(int numberOfBytesReceived)
{
  while (Wire.available())
  {
    //Record bytes to local array
    byte incoming = Wire.read();

    if (incoming == COMMAND_CHANGE_ADDRESS) //Set new I2C address
    {
      if (Wire.available())
      {
        setting_i2c_address = Wire.read();

        //Error check
        if (setting_i2c_address < 0x08 || setting_i2c_address > 0x77)
          continue; //Command failed. This address is out of bounds.

        EEPROM.write(LOCATION_I2C_ADDRESS, setting_i2c_address);

        //Our I2C address may have changed because of user's command
        startI2C(); //Determine the I2C address we should be using and begin listening on I2C bus
      }
    }
  }
}

//Send back a number of bytes via an array, max is 8 bytes at a time, 6 byte TAG ID and 2 byte time stamp.
//When the RFID module gets a request for data from the user, this function is called as an interrupt.
void requestEvent()
{
  loadNextTagToArray(); //Send response buffer
  for (byte x = 0 ; x < responseSize ; x++)
    Wire.write(responseBuffer[x]);
}

//Take the FIFO button press off the stack and load it into the transmit array
void loadNextTagToArray()
{
  if (oldestTag != newestTag)
  {
		for( int i = 0; i < 6; i ++ )
		{
			responseBuffer[i] = tagEvent[oldestTag].tagID[i];
		}
    unsigned long timeSincePressed = millis() - tagEvent[oldestTag].tagTime;//This is the time since last scan.
    responseBuffer[6] = timeSincePressed >> 24; //MSB
    responseBuffer[7] = timeSincePressed >> 16; 
    responseBuffer[8] = timeSincePressed >> 8;
    responseBuffer[9] = timeSincePressed; //LSB
    if ( ++oldestTag == MAX_TAG_STORAGE ) oldestTag = 0;
  }
  else
  {
    //No new ID's. 
		for( int i = 0; i < 8; i++ )
		{
			responseBuffer[i] = 0; 
		}
  }
}

//Reads the current system settings from EEPROM
//If anything looks weird, reset setting to default value
void readSystemSettings(void)
{
  //Read what I2C address we should use
  setting_i2c_address = EEPROM.read(LOCATION_I2C_ADDRESS);
  if (setting_i2c_address == 255)
  {
    setting_i2c_address = I2C_ADDRESS_DEFAULT; //By default, we listen for I2C_ADDRESS_DEFAULT
    EEPROM.write(LOCATION_I2C_ADDRESS, setting_i2c_address);
  }
}

//Begin listening on I2C bus as I2C slave using the global variable setting_i2c_address
void startI2C()
{
  Wire.end(); //Before we can change addresses we need to stop
  
  if (digitalRead(addrPin) == HIGH) //Default is HIGH, the jumper is closed with paste in production
    Wire.begin(setting_i2c_address); //Start I2C and answer calls using address from EEPROM
  else
    Wire.begin(I2C_ADDRESS_NO_JUMPER); //Force address to I2C_ADDRESS_NO_JUMPER if user has opened the solder jumper

  //The connections to the interrupts are severed when a Wire.begin occurs. So re-declare them.
  Wire.onReceive(receiveEvent);
  Wire.onRequest(requestEvent);
}

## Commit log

2019-01-08 Initial Commit (copy from Qwiic RFID)
    [Qwiic RFID - IDXXLA.brd, Qwiic RFID - IDXXLA.sch]
2019-01-15 Updates general trace layout, moves interrupt jumper to upper right, moves stat LED to TOP layer parallel with PWR LED
    * Adds SparkFun Flame and removes SparkX references
    * Changes version
    * Updates text to vector in schematic.
    * Updates Qwiic_RFID silk and power LED to something larger.
    [Qwiic RFID - IDXXLA.brd, Qwiic RFID - IDXXLA.sch]
2019-01-16 Adds better SparkFun silk, changes text to vector, and updates product name silk
    [Qwiic RFID - IDXXLA.brd, Qwiic RFID - IDXXLA.sch]
2019-01-16 Changes sparkFun logo to sparkFun + flame logo, adds dimensions for standoffs
    [Qwiic RFID - IDXXLA.brd, Qwiic RFID - IDXXLA.sch]
2019-01-17 Created panel V10
    [14250-Qwiic RFID - IDXXLA-Panel.GBL, 14250-Qwiic RFID - IDXXLA-Panel.GBO, 14250-Qwiic RFID - IDXXLA-Panel.GBP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]
2019-01-29 Updates panel to add TSTOP to MISO via on the ISP header.
    [14250-Qwiic RFID - IDXXLA-Panel.GBL, 14250-Qwiic RFID - IDXXLA-Panel.GBO, 14250-Qwiic RFID - IDXXLA-Panel.GBP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]
2019-02-28 New Folders
    -Move Arduino examples into firmware folder
    -Include separate folder for the Qwiic RFID's default firmware
2019-07-08 Removes example code and add link to Arduino Library in Readme
2021-02-02 Updates default i2c address for the Qwiic RFID to 0x13 as it was using an "illegal" address used for 10-bit addressing.
2021-02-02 Revert "Updates firmware to check default address against what's in memory"
    This reverts commit bb3fbe052572b12ccae124712ce3d4e583919edf.
    [Qwiic_RFID_IDXXLA.ino]
2024-11-26 Update Schematic to Reflect I2C Address Change
    [Qwiic RFID - IDXXLA.sch]
2025-07-15 Changes post-increment to a pre-increment
    The comparison checking whether the array is at the end its' length was
    incrementing the current value after doing the comparison
    (post-increment). This resulted in assigning values outside the bounds
    of the array.
2025-07-28 Rebuilds firmware, fixes name of folder to correctly reflect the processor
    [Qwiic_RFID_IDXXLA.ino]

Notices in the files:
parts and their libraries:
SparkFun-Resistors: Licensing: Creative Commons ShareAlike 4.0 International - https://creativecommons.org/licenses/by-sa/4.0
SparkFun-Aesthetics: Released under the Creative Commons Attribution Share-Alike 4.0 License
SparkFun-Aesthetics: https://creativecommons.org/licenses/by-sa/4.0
